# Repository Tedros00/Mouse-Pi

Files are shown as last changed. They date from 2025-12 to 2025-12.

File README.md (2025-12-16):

# Mouse-Pi

A compact, self-contained repository for the Mouse-Pi autonomous mobile robotics project. This README summarizes the repository purpose, quick-start instructions, and the folder layout so contributors and maintainers can find relevant code, models, and hardware files quickly.

## Quick start
- Install Python dependencies: run `pip install -r requirements.txt` in a suitable venv.
- Simulation: open the Gazebo worlds in `Gazebo/worlds/` and run the scripts in `Gazebo/scripts/`.
- Development: most robot algorithms and helpers live in `src/` and `examples/` — open those to run localization, SLAM, and planning examples.
- Embedded firmware: use PlatformIO workspace in `PlatformIO/` to build and flash microcontroller code.

## Folder structure
- `3D parts/` : SolidWorks assemblies, parts and exported STLs for 3D printing and mechanical design.
	- `SW/` contains individual SolidWorks part files.
- `Gazebo/` : Simulation assets (worlds, models, and helper scripts).
	- `models/robot/` contains the robot model used by Gazebo.
	- `scripts/` contains launch and utility scripts (e.g., `ekf.py`, `plan.py`).
- `PC/` : Host/PC-specific code and tools (if present, tools for mapping/visualization).
- `Pi/` : Pi-side scripts and deployment notes for running on Raspberry Pi.
- `examples/` : Example scripts grouped by purpose: Sensors, Interfaces, Models, SimulationEnv — useful starting points and demos.
- `PlatformIO/` : Embedded firmware source and configuration (`platformio.ini`, `src/`).
- `requirements.txt` : Python dependencies for simulation and algorithms.
- `results/` : Output artifacts such as generated maps and logs (e.g., `map.npy`, `trajectory.csv`).

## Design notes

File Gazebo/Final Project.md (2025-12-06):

# Final Project — Maze SLAM & Relocalization Challenge




## Overview
You will be given a **physical maze**. Your job is to:
1) **Build a simulated twin** of that maze in Gazebo using **`.sdf`** (simulate what you will test physically).
2) Make a mobile robot that can:
   - **Task A (Exploration + Mapping):** When released at a random pose, autonomously navigate and **build a map** of the environment.
   - **Task B (Relocalization + Goal Reach):** After the map exists, place the robot at a new, random pose; it must **relocalize** and **reach a specified target**.

You may use **any hardware/software** you like (ROS or NON ROS), but based on the LEGO NXT ROBOT. Teams with the **best time** (and valid maps) win.

## Learning Goals
- Apply **mobile-robot kinematics & control** to navigate safely (e.g., differential-drive constraints, nonholonomy).
- Implement **recursive state estimation** (prediction + update) for localization and mapping.
- Compare/choose between **Gaussian filters** (EKF/UKF) and **non‑parametric filters** (Particle) for SLAM and global relocalization.

---

## Project Tasks

### 1) Simulation Twin (SDF)
- Model the maze as an **SDF world** with proper wall geometry and friction; include your robot model and sensors (e.g., 2D lidar, IMU, other sensors...).
- Automate (With LLMs) a **reproducible launch** (ROS 2 or equivalent) that boots the world and your stack.

### 2) Task A — Exploration & Mapping
- From a **random initial pose**, the robot should **autonomously explore** and **produce a consistent map** (grid/occupancy or feature‑based).
- Use a **recursive estimator** with motion and measurement models (odometry/IMU + range/vision). Show prediction → correction clearly in your code/report.
- Deliver a **final map ** (e.g., picture or table format). 

### 3) Task B — Relocalization & Target Reach
- With the map available, start the robot at a **new random pose**; perform **global relocalization** and then **navigate** to a **given goal** (x, y, θ or zone).
- Robust global relocalization is encouraged to use **particle filters** (Monte Carlo Localization) (Through ROS2 or Custom)

---

## Constraints & Rules
- **Randomization:** Starting pose will be randomized in both A and B; your procedure must not depend on hard‑coded starts.
- **Sensing:** Any sensor suite is allowed; document models/noise. The estimator must fuse **control (uₜ)** and **measurements (zₜ)**.
- **Safety:** No collisions in sim, penalize sustained wall scraping; in lab, use a safe speed limit.
- **Reproducibility:** One‑command launch for sim and for system.

---

## What to Deliver

### Code & Simulation
- Public or zipped repo:
  - `worlds/maze.sdf` (`.sdf`) + any models
  - `launch/` scripts (ROS 2 or python or equivalent)
  - `README.md` with setup, **exact run commands**, and expected outputs

### Demonstrations
- **Sim demo:** Short screen‑capture: Task A (mapping) + Task B (relocalize & reach goal).
- **Physical demo:** Same two tasks on the real maze. You may pre‑map with your sim twin, but the **final judged map** must come from the physical run in Task A.

### Report (Explaining your strategy)
1. **Problem & system overview** (robot, sensors, actuation, kinematics).  
2. **Models:** motion model, sensor model, and **Bayes filter** formulation (state, control, measurement, belief).  
3. **Estimator choice:** KF/EKF/UKF vs Particle; justify with **linearity**, **uncertainty**, **multimodality**.  
4. **Mapping:** occupancy‑grid (log‑odds) or feature map; include update equations.  
5. **Navigation & control:** planner + controller; note non‑holonomic constraints if diff‑drive.  
6. **Experiments:** timing tables, success rate, map quality metrics (see below), failure cases, parameter sweeps.
7. **Ablations:** e.g., effect of particle count vs. convergence time; EKF vs UKF linearization quality.

---

## Scoring & Competition

### Timing (50%)
- **Task A time (20%)**: release → **map complete** (frontier exhausted or coverage ≥ 95%). Faster is better.
- **Task B time (20%)**: placement → **goal reached** within tolerance (e.g., ≤10 cm, ≤10°).
- **Start‑to‑finish integration (10%)**: minimal operator intervention; clean launch; robust recovery.

### Quality (30%)
- **Map quality (15%)**: occupancy grid IoU vs reference (or repeatability across two runs ± noise).
- **Localization accuracy (10%)**: final pose error at goal (or RMSE over a fiducial‑tracked segment).
- **Navigation smoothness (5%)**: path length vs shortest path; collision penalties.

### Engineering & Report (20%)
- **Clarity of models & estimators** (Bayes filter structure; linear vs nonlinear assumptions).  
- **Code quality & reproducibility** (README, configs, parameterization).  
- **Insightful analysis** (what worked/failed, evidence‑based choices).

**Penalties:** hard‑coded starts, non‑reproducible launches, unsafe behavior, large drift without recovery.  
**Tiebreakers:** smaller compute budget (CPU‑only vs GPU), cleaner code, clearer write‑up.

---

## Suggested Technical Path (Optional)
- **Kinematics & control:** Respect non‑holonomic constraints; implement a velocity controller and pose‑tracking law for your base.
- **Estimator selection:**
  - **EKF/UKF** if your models are near‑linear locally and you expect **unimodal** beliefs.
  - **Particle Filter** (MCL/AMCL‑like) if you expect **global uncertainty** or **multiple pose hypotheses** during relocalization; mind resampling and variance.
- **Mapping:** **Occupancy grid** with binary Bayes/Log‑odds updates; fuse lidar/range beams with inverse sensor models.
- **Exploration:** Frontier‑based or wall‑following with loop closures if available.
- **Validation:** Compare sim vs real logs; run with increased sensor noise to test robustness.  
- **Performance:** Tune particle count vs latency; for Gaussian filters, check linearization regime and innovation consistency.

---

## Logistics
- **Teams:** 2–3 students.
- **What to submit (single ZIP + PDF):**
  - Code repo (as above), **built map files**, short **sim video** (≤2 min), **report PDF** (≤6 pages).
- **Demo day:** Live **physical** runs for Task A and B on the lab maze under staff timing.
- **Academic integrity:** Cite all external packages and models you use.

---

### RPI HARDWARE

-USB C Cable for powering (5A high power)
-Power Bank To power remotely
-microSD card (A1/A2, 32–128 GB) + USB card reader
-micro-HDMI → HDMI cable (two if dual display)
-Active cooler or case with fan
-Raspberry Pi Camera Module 3 (Optional If you need visual feedback)

### Room Policy

-1 member per team gets room access.
-Don't use hardware not for the course (drones, other PIs, room hardware)

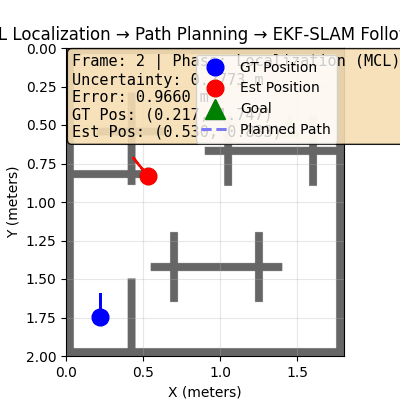
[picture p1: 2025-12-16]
out/PathPlan.gif

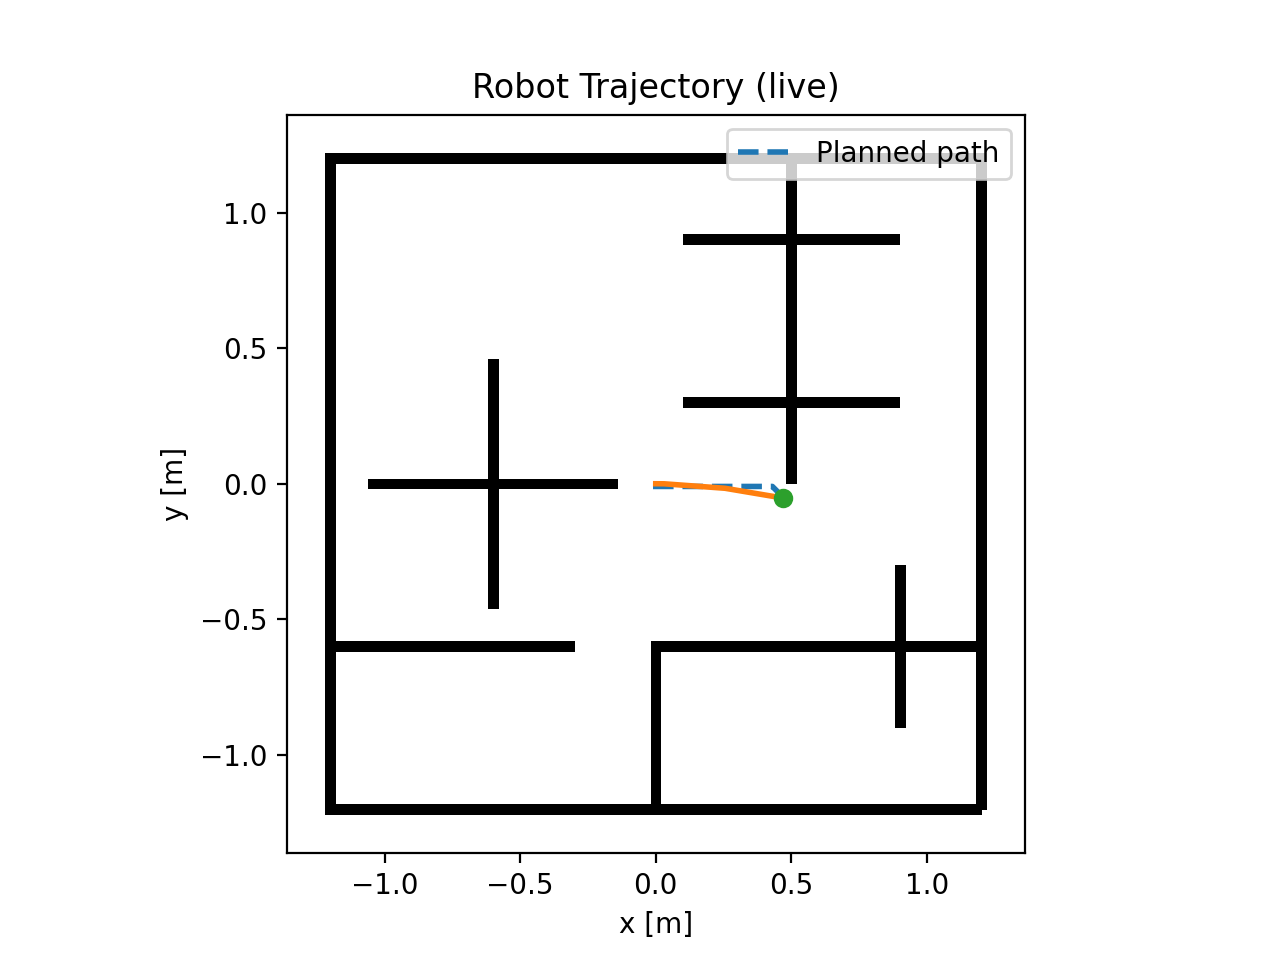
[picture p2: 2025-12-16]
Gazebo/scripts/trajectory.png

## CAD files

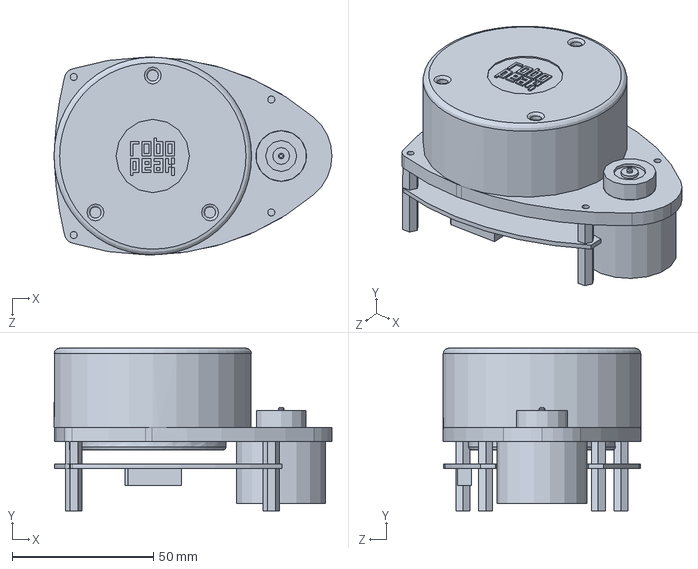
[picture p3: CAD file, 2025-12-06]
3D parts/SW/rplidar_main.SLDPRT
98.5 x 57.7 x 70.0 mm

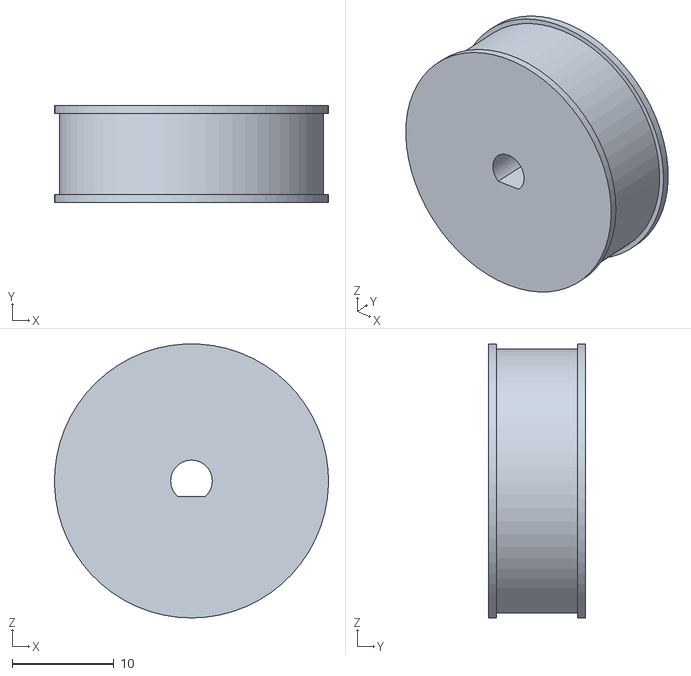
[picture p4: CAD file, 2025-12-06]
3D parts/STL/Motor pinion.STL
27.0 x 9.60 x 27.0

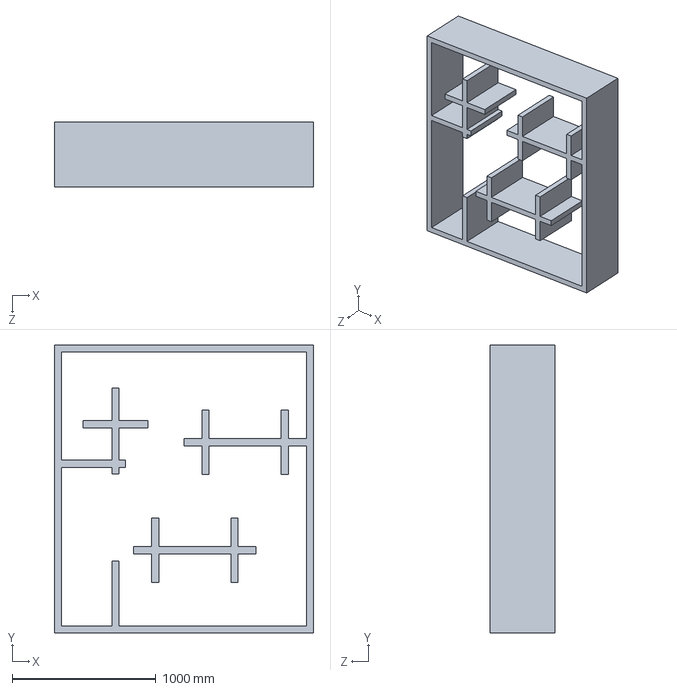
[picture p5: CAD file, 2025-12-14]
3D parts/SW/Maze.SLDPRT
1800.0 x 2000.0 x 450.0 mm

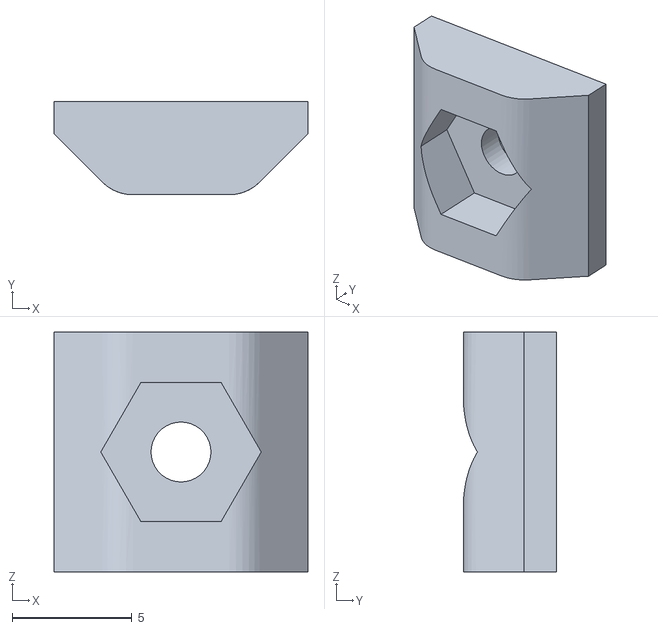
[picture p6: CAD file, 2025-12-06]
3D parts/STL/rack mount.STL
10.6 x 3.90 x 10.0

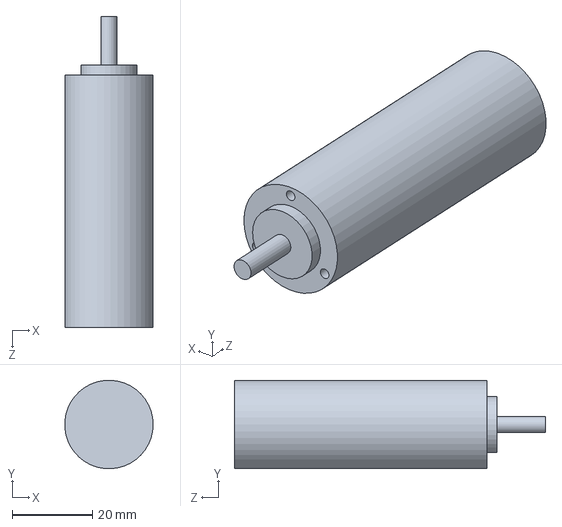
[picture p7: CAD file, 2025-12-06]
3D parts/SW/Motor.SLDPRT
22.0 x 22.0 x 77.3 mm

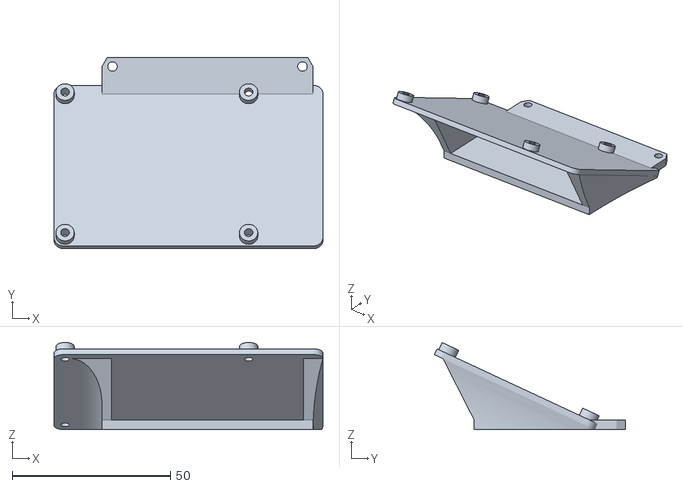
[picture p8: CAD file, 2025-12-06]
3D parts/STL/Pi mount.STL
85.0 x 60.5 x 27.5

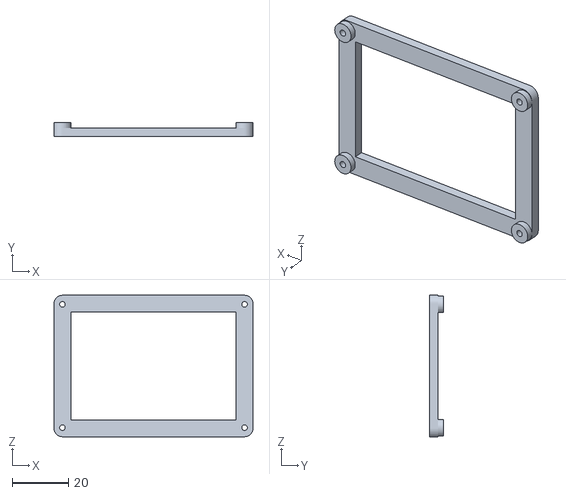
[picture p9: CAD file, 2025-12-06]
3D parts/STL/arduino mount.STL
71.0 x 5.00 x 50.5

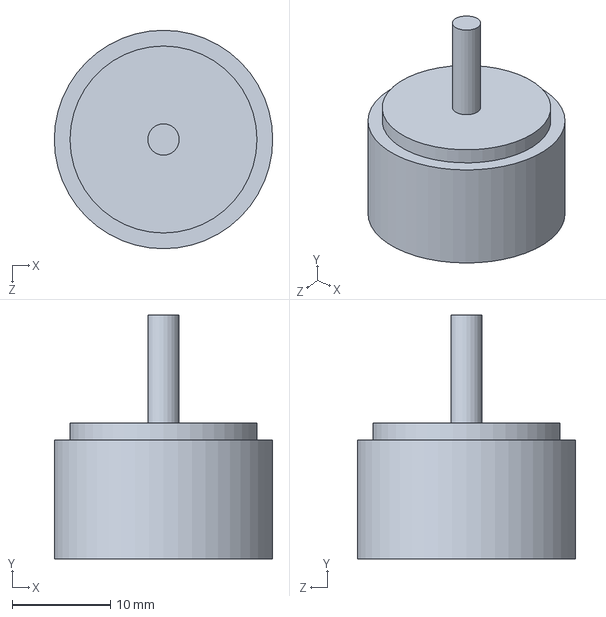
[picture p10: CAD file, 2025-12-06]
3D parts/SW/pot.SLDPRT
22.2 x 24.8 x 22.2 mm

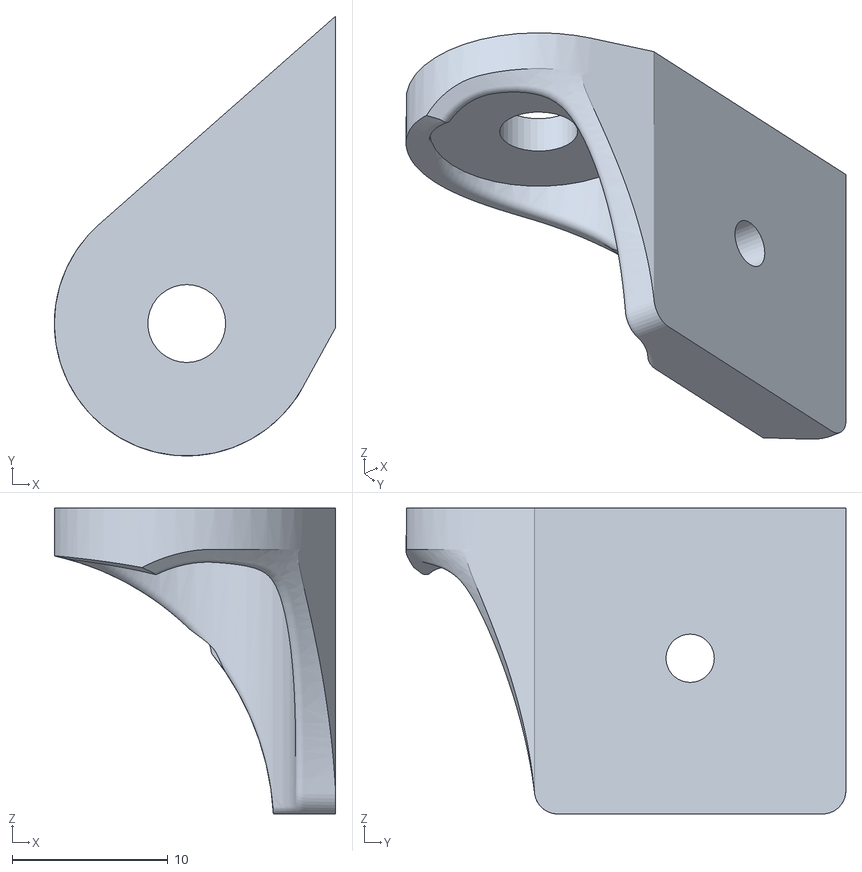
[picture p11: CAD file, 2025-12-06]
3D parts/STL/barrel mount.STL
18.1 x 28.2 x 19.6

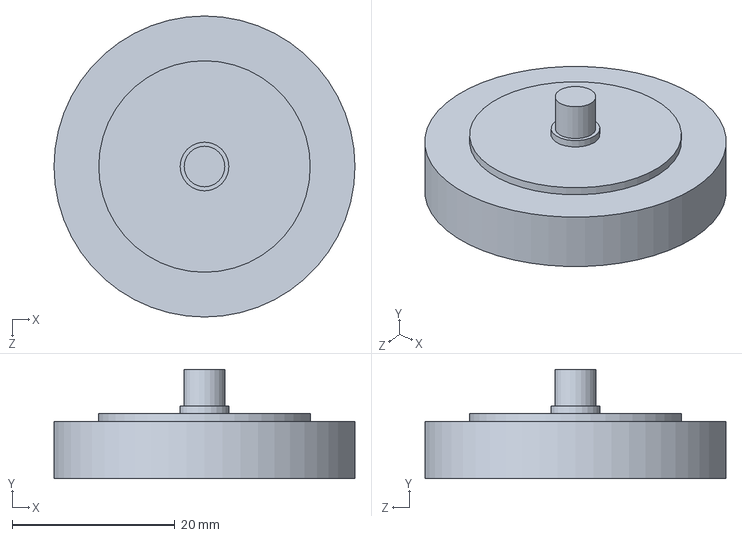
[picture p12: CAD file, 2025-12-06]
3D parts/SW/wheel.SLDPRT
37.0 x 13.4 x 37.0 mm

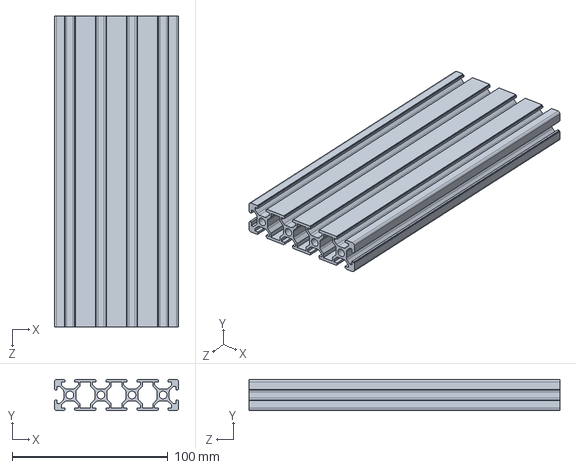
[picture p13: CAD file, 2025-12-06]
3D parts/SW/2080 Extrusion.SLDPRT
80.0 x 20.0 x 200.0 mm

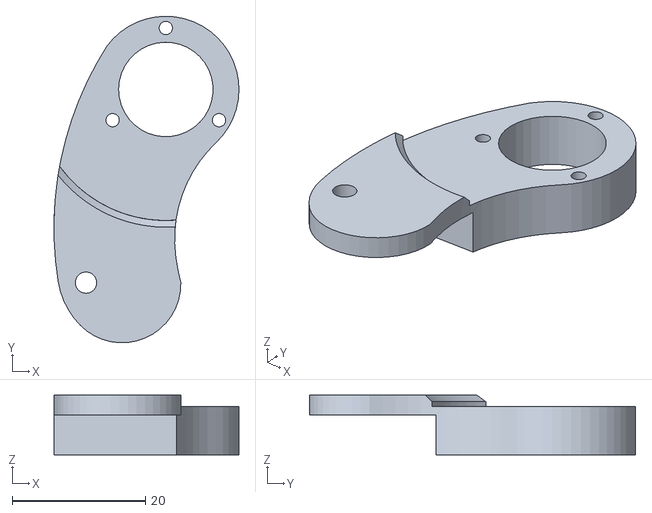
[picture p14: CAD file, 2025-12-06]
3D parts/STL/Motor Mount.STL
27.8 x 49.1 x 9.00

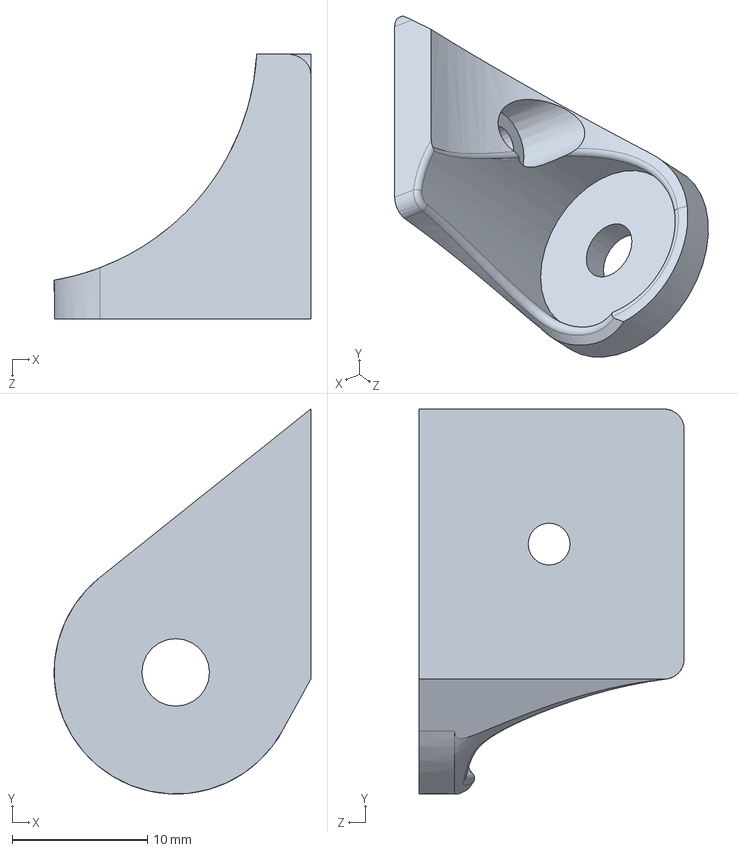
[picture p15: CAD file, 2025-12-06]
3D parts/SW/barrel mount.SLDPRT
19.0 x 28.5 x 19.6 mm

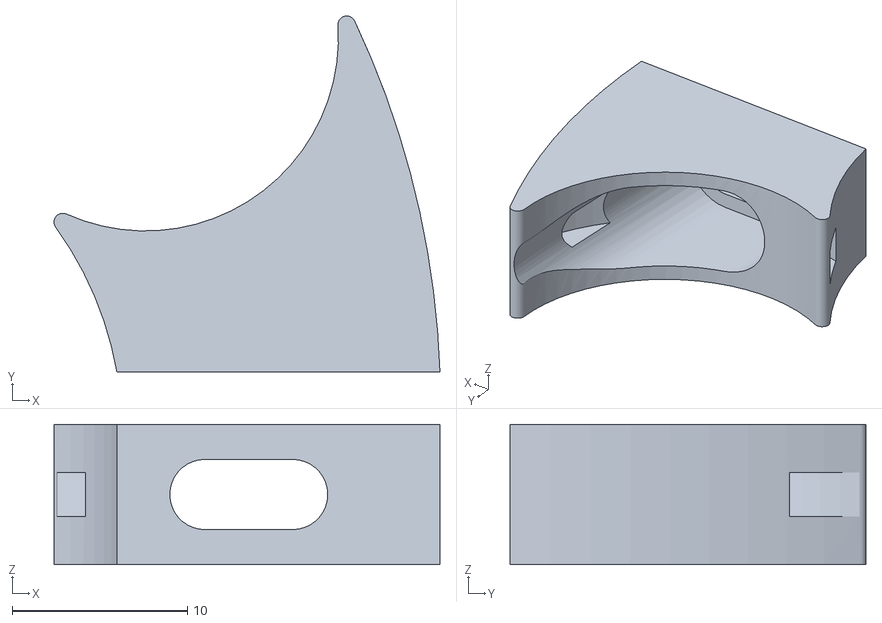
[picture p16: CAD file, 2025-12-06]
3D parts/STL/motor support.STL
22.0 x 20.3 x 8.00

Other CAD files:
3D parts/mouse.SLDASM
3D parts/SW/RaspberryPi5.SLDPRT
3D parts/STL/LidarMount.STL
3D parts/SW/arduino mount.SLDPRT
3D parts/STL/T-nut adapter.STL
3D parts/SW/T-nut adapter.SLDPRT
3D parts/SW/barrel.SLDPRT
3D parts/SW/motor pinion.SLDPRT

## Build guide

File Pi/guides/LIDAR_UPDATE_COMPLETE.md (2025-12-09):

# LIDAR Visualization Update - Complete Summary

## Overview

Your LIDAR streaming and visualization system has been completely upgraded to show **robot pose**, **scan statistics**, and **beam range finder model integration**.

## What's New ✨

### 1. Robot Pose Visualization
- Robot position displayed as **red circle**
- Robot heading shown with **red arrow**
- Automatic world-frame coordinate transformation
- Dynamic view that follows the robot

### 2. Scan Statistics
Each streamed frame now includes:
- **Distance metrics**: min, max, mean, median, standard deviation
- **Quality metrics**: minimum, maximum, mean signal strength
- **Point count**: number of valid measurements
- **Beam coverage**: percentage of beams with valid data

### 3. Beam Range Finder Model Integration
- **Normalized ranges** (0-1 scale) computed for all 360 beams
- Can be directly used with `beam_range_finder_model()`
- Optional beam coverage visualization (cyan lines)

### 4. Two Visualization Options

#### Option A: Simple (Fast)
```bash
python visualize_lidar_stream.py
```
- Single plot with scan points
- Robot pose overlay
- Basic statistics in title
- Low CPU usage

#### Option B: Advanced (Comprehensive)
```bash
python visualize_lidar_advanced.py
```
- 4-panel dashboard
- Distance distribution histogram
- Quality vs distance scatter plot
- Comprehensive statistics panel
- Beam coverage visualization

## Quick Start

### Step 1: Update Script with Your PC IP
Edit `examples/stream_lidar_to_pc.py`:
```python
PC_IP = '192.168.x.x'  # Your PC's IP address
```

### Step 2: Start Visualization on PC
```bash
# Choose one:
python visualize_lidar_stream.py         # Simple
python visualize_lidar_advanced.py       # Dashboard
```

### Step 3: Start Streaming on Robot
```bash
source /home/mouse/amr/bin/activate
python examples/stream_lidar_to_pc.py
```

### Step 4: Watch Real-time Data Flow
The visualization updates with:
- Scan points at current robot position
- Distance and quality statistics
- Frame counters and timestamps

## File Changes

### Modified Files
1. **`examples/stream_lidar_to_pc.py`**
   - Complete rewrite with pose/statistics support
   - New: `stream_lidar_with_pose()` function
   - New: Robot pose callback system
   - Sends: pose + stats + ranges per frame

2. **`examples/visualize_lidar_stream.py`**
   - Added robot pose visualization
   - Added statistics display
   - World-frame coordinate transformation
   - Dynamic axis scaling

### New Files
1. **`examples/visualize_lidar_advanced.py`**
   - 4-panel dashboard visualization
   - Distance distribution analysis
   - Quality metrics scatter plot
   - Comprehensive statistics panel

2. **`examples/validate_lidar_visualization.py`**
   - Comprehensive validation tests
   - Tests all components work together
   - Validates JSON serialization
   - All tests passing ✅

3. **Documentation Files**
   - `LIDAR_VISUALIZATION_README.md` - Detailed guide
   - `LIDAR_QUICK_START.py` - Quick reference
   - `LIDAR_VISUALIZATION_UPDATE.md` - Change summary

## Integration with Odometry

Update the `get_robot_pose()` callback in `stream_lidar_to_pc.py`:

```python
def get_robot_pose():
    # Option 1: From your motion model
    x, y, theta = your_motion_model.estimate_pose()
    
    # Option 2: From encoder feedback
    # x, y, theta = encoder_system.get_position()
    
    # Option 3: From particle filter
    # x, y, theta = particle_filter.get_best_estimate()
    
    return (x, y, theta)
```

The streaming automatically includes your pose estimates in every frame.

## Using with Beam Range Finder Model

The streamed `normalized_ranges` can be directly used:

```python
from ProbabilisticSensorModel import beam_range_finder_model
import numpy as np

# From streamed frame data
normalized_ranges = frame['normalized_ranges']
denormalized = np.array(normalized_ranges) * 5000  # Convert to mm

# Evaluate likelihood for particle filter
prob = beam_range_finder_model(
    robot_pose=(frame['robot_pose']['x'], 
                frame['robot_pose']['y'],
                frame['robot_pose']['theta']),
    z=denormalized,
    map_data=your_map,
    compute_from_map=your_ray_cast_function,
    max_range=5000
)

# Use probability for particle weighting
particle_weights[i] = prob
```

## Data Format

Each frame contains:
```json
{
  "timestamp": 1702190000.123,
  "frame": 42,
  "robot_pose": {"x": 100, "y": 200, "theta": 0.5},
  "num_points": 1000,
  "points": [[angle, distance, quality], ...],
  "statistics": {
    "min_distance": 200,
    "max_distance": 5000,
    "mean_distance": 1200,
    "median_distance": 1000,
    "std_distance": 400,
    "quality_mean": 12.5,
    "quality_min": 0,
    "quality_max": 15
  },
  "normalized_ranges": [0.1, 0.11, ..., 0.09]
}
```

## Performance

| Metric | Value |
|---|---|
| Data per frame | ~50KB |
| Update rate | 5-10 Hz |
| Network bandwidth | ~500KB/s |
| CPU (simple viz) | ~5% |
| CPU (dashboard) | ~15% |

## Testing Status

✅ All validation tests passed:
- Stream data format
- Pose transformation
- Statistics computation
- Normalized ranges
- Visualization compatibility

## What the Visualizations Show

### Simple Visualization
```
┌──────────────────────┐
│  Scan Points (dots)  │
│  - Colored by quality │
│  - Red circle = robot│
│  - Red arrow = heading
│  - Statistics in title
└──────────────────────┘
```

### Advanced Dashboard
```
┌──────────────────┬──────────────────┐
│ Scan Viz         │ Distance Hist    │
│ + Robot Pose     │ + Mean/Median    │
├──────────────────┼──────────────────┤
│ Quality vs Dist  │ Statistics Panel │
│ (Scatter plot)   │ (Text Info)      │
└──────────────────┴──────────────────┘
```

## Known Limitations & Solutions

| Issue | Solution |
|---|---|
| Beam coverage not visible | Increase alpha in `draw_beam_coverage()` |
| Slow on low-end PC | Use simple visualization instead |
| Statistics seem wrong | Verify LIDAR filters and odometry |
| Connection fails | Start visualization before streaming |

## Next Steps

1. ✅ **Test with current setup** - Works out of the box at origin
2. 🔄 **Add your odometry** - Implement `get_robot_pose()` callback
3. 📊 **Validate statistics** - Compare with known environments
4. 🗺️ **Add map overlay** - Extend visualization with obstacle map
5. 🔍 **Tune beam model** - Use statistics to validate sensor parameters

## Files You Need to Know

**Robot Side:**
- `examples/stream_lidar_to_pc.py` - Run on AMR

**PC Side (Pick One):**
- `examples/visualize_lidar_stream.py` - Simple, fast
- `examples/visualize_lidar_advanced.py` - Detailed analysis

**Testing/Validation:**
- `examples/validate_lidar_visualization.py` - Verify everything works

**Documentation:**
- `LIDAR_VISUALIZATION_README.md` - Full reference
- `LIDAR_QUICK_START.py` - Code examples
- `LIDAR_VISUALIZATION_UPDATE.md` - Change log

## Support & Debugging

**Check console output on robot:**
```
Frame 5: 1000 points | Distance: 1200±400mm | Pose: (0.0, 0.0, 0.0°)
Frame 10: 995 points | Distance: 1210±410mm | Pose: (100.0, 50.0, 15.2°)
```

**Common fixes:**
1. Connection refused → Start visualization first
2. No points visible → Check LIDAR connected, pose reasonable
3. Statistics wrong → Verify filters, odometry callback
4. Slow updates → Use simple viz, reduce update frequency

## Summary

You now have a complete real-time LIDAR visualization system with:
- ✅ Robot pose tracking
- ✅ Comprehensive statistics
- ✅ Beam range finder model integration
- ✅ Two visualization levels (simple + advanced)
- ✅ Easy odometry integration
- ✅ World-frame coordinate display
- ✅ Full validation testing

Ready to use! 🚀

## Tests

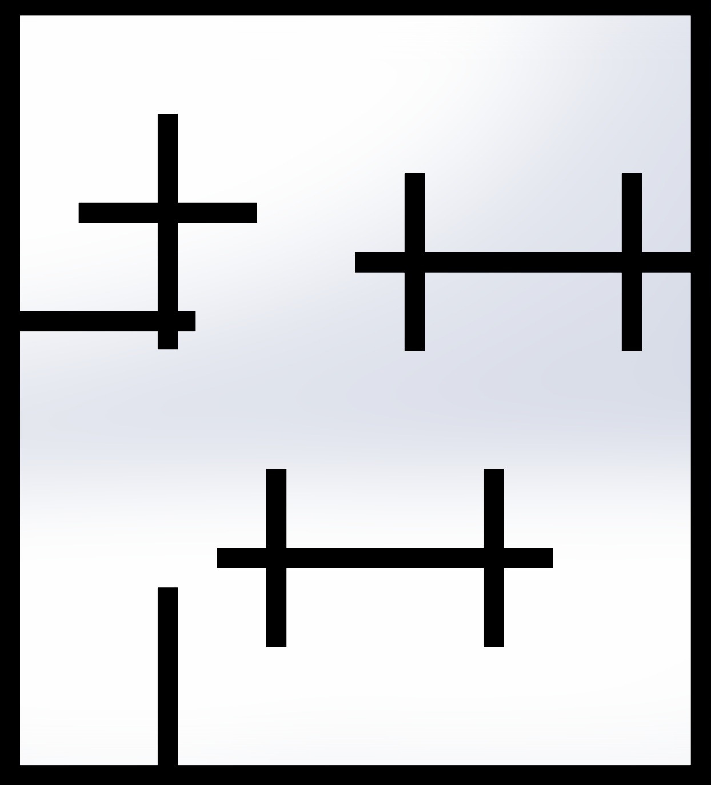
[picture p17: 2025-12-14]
Pi/examples/SimulationEnv/TestMaze.JPG

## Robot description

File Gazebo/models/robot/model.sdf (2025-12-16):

<?xml version="1.0"?>
<sdf version="1.9">
  <model name="robot">

    <pose>0 0 0.05 0 0 0</pose>

    <!-- ================= BASE ================= -->
    <link name="base_link">
      <pose>0 0 0.05 0 0 0</pose>

      <inertial>
        <mass>1.5</mass>
        <inertia>
          <ixx>0.02</ixx>
          <iyy>0.02</iyy>
          <izz>0.04</izz>
        </inertia>
      </inertial>

      <collision name="base_collision">
        <geometry>
          <box>
            <size>0.18 0.14 0.10</size>
          </box>
        </geometry>
      </collision>

      <visual name="base_visual">
        <geometry>
          <box>
            <size>0.18 0.14 0.10</size>
          </box>
        </geometry>
        <material>
          <ambient>0.8 0.8 0.8 1</ambient>
          <diffuse>0.8 0.8 0.8 1</diffuse>
        </material>
      </visual>

      <!-- IMU -->
      <sensor name="imu" type="imu">
        <always_on>true</always_on>
        <update_rate>200</update_rate>
        <topic>/model/robot/imu</topic>
      </sensor>

      <!-- GPS -->
      <sensor name="gps" type="gps">
        <always_on>true</always_on>
        <update_rate>5</update_rate>
        <topic>/model/robot/gps</topic>
      </sensor>

      <!-- 2D LIDAR -->
      <sensor name="lidar" type="gpu_lidar">
        <pose>0.09 0 0.12 0 0 0</pose>
        <update_rate>10</update_rate>
        <topic>/scan</topic>

        <lidar>
          <scan>
            <horizontal>
              <samples>720</samples>
              <min_angle>-3.14159</min_angle>
              <max_angle>3.14159</max_angle>
            </horizontal>
          </scan>
          <range>
            <min>0.05</min>
            <max>6.0</max>
          </range>
        </lidar>
      </sensor>
    </link>

    <!-- ================= LEFT WHEEL ================= -->
    <link name="left_wheel">
      <!-- IMPORTANT: roll = 1.5708 to align cylinder axis with Y -->
      <pose>0 0.07 0.03 1.5708 0 0</pose>

      <inertial>
        <mass>0.2</mass>
        <inertia>
          <ixx>0.001</ixx>
          <iyy>0.001</iyy>
          <izz>0.001</izz>
        </inertia>
      </inertial>

      <collision name="collision">
        <geometry>
          <cylinder>
            <radius>0.03</radius>
            <length>0.02</length>
          </cylinder>
        </geometry>
      </collision>

      <visual name="visual">
        <geometry>
          <cylinder>
            <radius>0.03</radius>
            <length>0.02</length>
          </cylinder>
        </geometry>
        <material>
          <ambient>0.1 0.1 0.1 1</ambient>
        </material>
      </visual>
    </link>

    <!-- ================= RIGHT WHEEL ================= -->
    <link name="right_wheel">
      <pose>0 -0.07 0.03 1.5708 0 0</pose>

      <inertial>
        <mass>0.2</mass>
        <inertia>
          <ixx>0.001</ixx>
          <iyy>0.001</iyy>
          <izz>0.001</izz>
        </inertia>
      </inertial>

      <collision name="collision">
        <geometry>
          <cylinder>
            <radius>0.03</radius>
            <length>0.02</length>
          </cylinder>
        </geometry>
      </collision>

      <visual name="visual">
        <geometry>
          <cylinder>
            <radius>0.03</radius>
            <length>0.02</length>
          </cylinder>
        </geometry>
        <material>
          <ambient>0.1 0.1 0.1 1</ambient>
        </material>
      </visual>
    </link>

    <!-- ================= JOINTS ================= -->
    <joint name="left_wheel_joint" type="revolute">
      <parent>base_link</parent>
      <child>left_wheel</child>
      <axis>
        <xyz>0 1 0</xyz>
      </axis>
    </joint>

    <joint name="right_wheel_joint" type="revolute">
      <parent>base_link</parent>
      <child>right_wheel</child>
      <axis>
        <xyz>0 1 0</xyz>
      </axis>
    </joint>

    <!-- ================= DIFF DRIVE ================= -->
    <plugin filename="gz-sim-diff-drive-system" name="gz::sim::systems::DiffDrive">

      <left_joint>left_wheel_joint</left_joint>
      <right_joint>right_wheel_joint</right_joint>

      <wheel_separation>0.14</wheel_separation>
      <wheel_radius>0.03</wheel_radius>

      <cmd_vel_topic>/model/robot/cmd_vel</cmd_vel_topic>
      <odom_topic>/model/robot/odom</odom_topic>
      <odom_publish_frequency>50</odom_publish_frequency>

      <publish_tf>false</publish_tf>
    </plugin>

  </model>
</sdf>

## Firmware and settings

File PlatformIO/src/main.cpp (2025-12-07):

#include <Arduino.h>

// Motor A (connected to EN_A, IN1, IN2)
#define EN_A A0
#define IN1 11
#define IN2 10

// Motor B (connected to EN_B, IN3, IN4)
#define EN_B A1
#define IN3 7
#define IN4 8

// PWM Frequency control
// Lowering frequency gives more torque at low speeds but may cause buzzing
// Higher frequency is smoother but may need higher minimum PWM
#define PWM_FREQUENCY 490  // Default Arduino frequency; try 122, 245, 490, 980, 3920, 7840, 15625 Hz

// Potentiometers
#define POT1 A2
#define POT2 A3

// Forward declaration of PWM frequency function
void setPwmFrequency(int pin, int divisor);

void setup() {
  Serial.begin(115200);  // Initialize serial communication at 115200 baud
  
  // Configure motor control pins as outputs
  pinMode(EN_A, OUTPUT);
  pinMode(IN1, OUTPUT);
  pinMode(IN2, OUTPUT);
  
  pinMode(EN_B, OUTPUT);
  pinMode(IN3, OUTPUT);
  pinMode(IN4, OUTPUT);
  
  // Configure potentiometers as inputs
  pinMode(POT1, INPUT);
  pinMode(POT2, INPUT);
  
  // Set PWM frequency for motor pins (pins 9 and 10 share timer1, 3 and 11 share timer2)
  // For pins 11 (IN2/EN_A) and 3 (IN4/EN_B): change timer2 frequency
  setPwmFrequency(11, 1);  // Divider 1 = 31.4 kHz (too high, audible noise reduced)
  setPwmFrequency(3, 1);   // Divider 1 = 31.4 kHz
  
  // Initialize motors to stop
  digitalWrite(IN1, LOW);
  digitalWrite(IN2, LOW);
  digitalWrite(IN3, LOW);
  digitalWrite(IN4, LOW);
  analogWrite(EN_A, 0);
  analogWrite(EN_B, 0);
}

void setMotor(int pwmPin, int in1Pin, int in2Pin, int dutyCycle) {
  // dutyCycle ranges from -100 to 100
  // Positive values: IN1 HIGH, IN2 LOW
  // Negative values: IN1 LOW, IN2 HIGH
  
  // Define minimum and maximum PWM values for motor control
  // MIN_PWM: minimum speed threshold to start motor rotation (adjust to your motor's needs)
  // MAX_PWM: typically 255, but can be reduced to limit maximum speed
  const int MIN_PWM = 36;    // You found motors activate at 36
  const int MAX_PWM = 255;
  
  // Map duty cycle to PWM range with dead band
  int pwmValue = 0;
  if (dutyCycle != 0) {
    // Map 1-100% to MIN_PWM-MAX_PWM range
    pwmValue = MIN_PWM + (abs(dutyCycle) - 1) * (MAX_PWM - MIN_PWM) / 99;
    pwmValue = constrain(pwmValue, MIN_PWM, MAX_PWM);
  }
  
  if (dutyCycle > 0) {
    // Forward direction
    digitalWrite(in1Pin, HIGH);
    digitalWrite(in2Pin, LOW);
  } else if (dutyCycle < 0) {
    // Reverse direction
    digitalWrite(in1Pin, LOW);
    digitalWrite(in2Pin, HIGH);
  } else {
    // Stop
    digitalWrite(in1Pin, LOW);
    digitalWrite(in2Pin, LOW);
  }
  
  analogWrite(pwmPin, pwmValue);
}

void loop() {
  // Read potentiometer values
  int pot1Value = analogRead(POT1);
  int pot2Value = analogRead(POT2);
  
  // Print potentiometer values
  Serial.print("Pot1: ");
  Serial.print(pot1Value);
  Serial.print(" | Pot2: ");
  Serial.println(pot2Value);
  
  if (Serial.available() > 0) {
    // Read the input string until newline
    String input = Serial.readStringUntil('\n');
    input.trim();
    
    // Parse the two integers
    int spaceIndex = input.indexOf(' ');
    
    if (spaceIndex > 0) {
      int dc1 = input.substring(0, spaceIndex).toInt();
      int dc2 = input.substring(spaceIndex + 1).toInt();
      
      // Constrain values to -100 to 100
      dc1 = constrain(dc1, -100, 100);
      dc2 = constrain(dc2, -100, 100);
      
      // Set motor speeds
      setMotor(EN_A, IN1, IN2, dc1);
      setMotor(EN_B, IN3, IN4, dc2);
      
      // Echo back the values for confirmation
      Serial.print("Motor A: ");
      Serial.print(dc1);
      Serial.print("% | Motor B: ");
      Serial.print(dc2);
      Serial.println("%");
    }
  }
  
  delay(100);  // Print potentiometer values every 100ms
}

// Set PWM frequency on Arduino pins
// Divisor: 1=31.4kHz, 2=3.9kHz, 3=980Hz, 4=490Hz, 5=245Hz, 6=122Hz, 7=61Hz
void setPwmFrequency(int pin, int divisor) {
  byte mode;
  if(pin == 5 || pin == 6 || pin == 9 || pin == 10) {
    switch(divisor) {
      case 1: mode = 0x01; break;
      case 2: mode = 0x02; break;
      case 3: mode = 0x03; break;
      case 4: mode = 0x04; break;
      case 5: mode = 0x05; break;
      case 6: mode = 0x06; break;
      case 7: mode = 0x07; break;
      default: return;
    }
    TCCR1B = (TCCR1B & 0b11111000) | mode;
  }
  else if(pin == 3 || pin == 11) {
    switch(divisor) {
      case 1: mode = 0x01; break;
      case 2: mode = 0x02; break;
      case 3: mode = 0x03; break;
      case 4: mode = 0x04; break;
      case 5: mode = 0x05; break;
      case 6: mode = 0x06; break;
      case 7: mode = 0x07; break;
      default: return;
    }
    TCCR2B = (TCCR2B & 0b11111000) | mode;
  }
}

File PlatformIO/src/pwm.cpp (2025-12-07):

#include <Arduino.h>

// Motor A (connected to EN_A, IN1, IN2)
#define EN_A A0
#define IN1 11
#define IN2 10

// Motor B (connected to EN_B, IN3, IN4)
#define EN_B A1
#define IN3 7
#define IN4 8

// Potentiometers
#define POT1 A2
#define POT2 A3

// ============================================================================
// Hardware PWM Interrupt-Based Control
// ============================================================================

// PWM Configuration
const uint16_t PWM_FREQUENCY_HZ = 10000;           // PWM frequency in Hz

// PWM state for each motor (0-255, where 0=0% duty, 255=100% duty)
volatile uint8_t pwm_motor_a = 0;  // Motor A PWM value (0-255)
volatile uint8_t pwm_motor_b = 0;  // Motor B PWM value (0-255)

// PWM direction control (true = positive direction, false = negative direction)
volatile bool dir_motor_a = true;   // true: IN1 gets PWM, false: IN2 gets PWM
volatile bool dir_motor_b = true;   // true: IN3 gets PWM, false: IN4 gets PWM

// Internal timing state for interrupt handler
volatile uint16_t pwm_timer_count = 0;  // Current timer tick count within PWM period

// ============================================================================
// Timer1 Interrupt Handler - Runs at 16kHz (62.5us intervals)
// Generates PWM signals based on current pwm_motor_a and pwm_motor_b values
// ============================================================================
ISR(TIMER1_COMPA_vect) {
  // Motor A control: EN_A gets PWM, IN1/IN2 set direction
  if (pwm_timer_count <= pwm_motor_a) {
    digitalWrite(EN_A, HIGH);  // Enable motor (PWM high)
  } else {
    digitalWrite(EN_A, LOW);   // Disable motor (PWM low)
  }
  
  // Set direction for Motor A
  if (dir_motor_a) {
    digitalWrite(IN1, HIGH);   // Forward direction
    digitalWrite(IN2, LOW);
  } else {
    digitalWrite(IN1, LOW);    // Reverse direction
    digitalWrite(IN2, HIGH);
  }
  
  // Motor B control: EN_B gets PWM, IN3/IN4 set direction
  if (pwm_timer_count <= pwm_motor_b) {
    digitalWrite(EN_B, HIGH);  // Enable motor (PWM high)
  } else {
    digitalWrite(EN_B, LOW);   // Disable motor (PWM low)
  }
  
  // Set direction for Motor B
  if (dir_motor_b) {
    digitalWrite(IN3, HIGH);   // Forward direction
    digitalWrite(IN4, LOW);
  } else {
    digitalWrite(IN3, LOW);    // Reverse direction
    digitalWrite(IN4, HIGH);
  }
  
  // Increment timer counter and reset at period end
  pwm_timer_count++;
  if (pwm_timer_count >= 256) {
    pwm_timer_count = 0;
  }
}

// ============================================================================
// Public API Functions
// ============================================================================

/**
 * Initialize Timer1 for PWM interrupt-based control
 * Sets up CTC mode with interrupts at 16kHz
 */
void pwm_init() {
  // Timer1 Configuration for CTC mode
  TCCR1A = 0;                     // Normal mode
  TCCR1B = 0;                     // Reset
  TCNT1 = 0;                      // Reset counter
  
  // Set CTC mode (WGM12 = 1)
  TCCR1B |= (1 << WGM12);
  
  // Set prescaler to 1 (no prescaling) for 16MHz -> 16MHz ticks
  TCCR1B |= (1 << CS10);
  
  // Set compare value for 16kHz interrupt (16000000 / 16000 = 1000 ticks)
  OCR1A = 1000;
  
  // Enable Timer1 Compare A interrupt
  TIMSK1 |= (1 << OCIE1A);
}

/**
 * Set PWM value for Motor A
 * @param pwm_value: 0-255 (0% to 100% duty cycle)
 *        Sign determines direction: positive -> IN1 active, negative -> IN2 active
 */
void setPWM_MotorA(int8_t pwm_value) {
  if (pwm_value >= 0) {
    dir_motor_a = true;              // IN1 carries PWM signal
    pwm_motor_a = constrain(pwm_value, 0, 255);
  } else {
    dir_motor_a = false;             // IN2 carries PWM signal
    pwm_motor_a = constrain(-pwm_value, 0, 255);
  }
}

/**
 * Set PWM value for Motor B
 * @param pwm_value: 0-255 (0% to 100% duty cycle)
 *        Sign determines direction: positive -> IN3 active, negative -> IN4 active
 */
void setPWM_MotorB(int8_t pwm_value) {
  if (pwm_value >= 0) {
    dir_motor_b = true;              // IN3 carries PWM signal
    pwm_motor_b = constrain(pwm_value, 0, 255);
  } else {
    dir_motor_b = false;             // IN4 carries PWM signal
    pwm_motor_b = constrain(-pwm_value, 0, 255);
  }
}

/**
 * Stop both motors immediately
 */
void stopAllMotors() {
  pwm_motor_a = 0;
  pwm_motor_b = 0;
  digitalWrite(IN1, LOW);
  digitalWrite(IN2, LOW);
  digitalWrite(IN3, LOW);
  digitalWrite(IN4, LOW);
}

// PWM Frequency control
void setup() {
  Serial.begin(115200);  // Initialize serial communication at 115200 baud
  
  // Initialize hardware PWM interrupt system
  pwm_init();
  
  // Configure EN pins as outputs (controlled by interrupt)
  pinMode(EN_A, OUTPUT);
  pinMode(EN_B, OUTPUT);
  digitalWrite(EN_A, LOW);
  digitalWrite(EN_B, LOW);
  
  // Configure potentiometers as inputs
  pinMode(POT1, INPUT);
  pinMode(POT2, INPUT);
  
  // Initialize motors to stop (0% duty cycle - pins LOW, not attached to servo)
  pinMode(IN1, OUTPUT);
  pinMode(IN2, OUTPUT);
  pinMode(IN3, OUTPUT);
  pinMode(IN4, OUTPUT);
  digitalWrite(IN1, LOW);
  digitalWrite(IN2, LOW);
  digitalWrite(IN3, LOW);
  digitalWrite(IN4, LOW);
}

void loop() {
  if (Serial.available() > 0) {
    // Read the input character or string
    char inputChar = Serial.read();
    
    // Check if 'R' was received to send potentiometer values
    if (inputChar == 'R' || inputChar == 'r') {
      int pot1Value = analogRead(POT1);
      int pot2Value = analogRead(POT2);
      
      Serial.print(pot1Value);
      Serial.print(" ");
      Serial.println(pot2Value);
    }
    // Check if it's a digit (start of PWM command)
    else if (isdigit(inputChar) || inputChar == '-') {
      // Read the rest of the line
      String input = String(inputChar) + Serial.readStringUntil('\n');
      input.trim();
      
      // Parse the two integers
      int spaceIndex = input.indexOf(' ');
      
      if (spaceIndex > 0) {
        int dc1 = input.substring(0, spaceIndex).toInt();
        int dc2 = input.substring(spaceIndex + 1).toInt();
        
        // Map -100 to 100 range to -255 to 255 for PWM
        dc1 = constrain(dc1, -255, 255);
        dc2 = constrain(dc2, -255, 255);
        
        // Convert duty cycle percentage to PWM value (0-255)
        int pwm1 = map(dc1, -255, 255, -100, 100);
        int pwm2 = map(dc2, -255, 255, -100, 100);
        
        // Set motor PWM values
        setPWM_MotorA(pwm1);
        setPWM_MotorB(pwm2);
      }
    }
  }
}
  

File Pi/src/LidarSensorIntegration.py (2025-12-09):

"""
Integration module for LIDAR scans with beam range finder model.

Converts LIDAR scans to range measurements compatible with the probabilistic sensor model.
"""

import numpy as np
from ProbabilisticSensorModel import beam_range_finder_model, likelyhood_field_model


def lidar_scan_to_ranges(scan_data: np.ndarray, 
                         robot_pose: tuple,
                         num_beams: int = 360,
                         max_range: float = 5000) -> np.ndarray:
    """
    Convert raw LIDAR scan data to a normalized range array for sensor model.
    
    Interpolates scan data to a uniform angular distribution.
    
    Args:
        scan_data (np.ndarray): Nx3 array [angle, distance, quality]
        robot_pose (tuple): Robot pose (x, y, theta) - used for coordinate transformation
        num_beams (int): Number of beams to resample to (default: 360)
        max_range (float): Maximum range in mm (default: 5000)
    
    Returns:
        np.ndarray: Normalized range measurements (0-1 scale) for num_beams angles
    """
    if len(scan_data) == 0:
        return np.full(num_beams, 1.0)  # Return max range if no data
    
    # Extract angles and distances from scan
    angles = scan_data[:, 0]
    distances = scan_data[:, 1]
    
    # Normalize distances to 0-1 range
    normalized_distances = np.clip(distances / max_range, 0, 1)
    
    # Create uniform angular grid for resampling
    uniform_angles = np.linspace(0, 360, num_beams, endpoint=False)
    
    # Interpolate distances for uniform angles
    resampled_distances = np.interp(uniform_angles, angles, normalized_distances, 
                                    left=1.0, right=1.0)
    
    return resampled_distances


def lidar_scan_to_cartesian(scan_data: np.ndarray, 
                            robot_pose: tuple) -> np.ndarray:
    """
    Convert LIDAR scan to cartesian coordinates relative to world frame.
    
    Args:
        scan_data (np.ndarray): Nx3 array [angle, distance, quality]
        robot_pose (tuple): Robot pose (x, y, theta) in world frame
    
    Returns:
        np.ndarray: Nx2 array of [x, y] points in world frame
    """
    x_robot, y_robot, theta_robot = robot_pose
    
    angles_deg = scan_data[:, 0]
    distances_mm = scan_data[:, 1]
    
    # Convert angles to radians and add robot orientation
    angles_rad = np.radians(angles_deg) + theta_robot
    
    # Convert to cartesian in robot frame
    x_robot_frame = distances_mm * np.cos(angles_rad)
    y_robot_frame = distances_mm * np.sin(angles_rad)
    
    # Transform to world frame
    x_world = x_robot + x_robot_frame * np.cos(theta_robot) - y_robot_frame * np.sin(theta_robot)
    y_world = y_robot + x_robot_frame * np.sin(theta_robot) + y_robot_frame * np.cos(theta_robot)
    
    return np.column_stack([x_world, y_world])


def filter_scan_by_quality(scan_data: np.ndarray, 
                          min_quality: int = 5) -> np.ndarray:
    """
    Filter LIDAR scan points by signal quality.
    
    Args:
        scan_data (np.ndarray): Nx3 array [angle, distance, quality]
        min_quality (int): Minimum quality threshold (0-255)
    
    Returns:
        np.ndarray: Filtered scan data
    """
    if scan_data.shape[1] < 3:
        return scan_data
    
    quality = scan_data[:, 2]
    mask = quality >= min_quality
    return scan_data[mask]


def filter_scan_by_distance(scan_data: np.ndarray,
                           min_distance: float = 0,
                           max_distance: float = 5000) -> np.ndarray:
    """
    Filter LIDAR scan points by distance range.
    
    Args:
        scan_data (np.ndarray): Nx3 array [angle, distance, quality]
        min_distance (float): Minimum distance in mm
        max_distance (float): Maximum distance in mm
    
    Returns:
        np.ndarray: Filtered scan data
    """
    distances = scan_data[:, 1]
    mask = (distances >= min_distance) & (distances <= max_distance)
    return scan_data[mask]


def evaluate_scan_with_sensor_model(scan_data: np.ndarray,
                                    robot_pose: tuple,
                                    map_data,
                                    compute_from_map,
                                    num_beams: int = 360,
                                    max_range: float = 5000,
                                    sensor_params: dict = None) -> float:
    """
    Evaluate a LIDAR scan using the beam range finder model.
    
    Computes probability of observation given robot pose and map.
    
    Args:
        scan_data (np.ndarray): Nx3 array [angle, distance, quality]
        robot_pose (tuple): Robot pose (x, y, theta)
        map_data: Map data for sensor model evaluation
        compute_from_map: Function to compute expected range from map
        num_beams (int): Number of beams for evaluation
        max_range (float): Maximum range in mm
        sensor_params (dict): Sensor model parameters
                            - 'min_theta': minimum beam angle (default: -π/2)
                            - 'max_theta': maximum beam angle (default: π/2)
                            - 'sigma_hit': hit component std dev (default: 0.2)
                            - 'lambda_short': short component lambda (default: 0.1)
                            - 'z_hit': hit weight (default: 0.7)
                            - 'z_short': short weight (default: 0.1)
                            - 'z_max': max range weight (default: 0.1)
                            - 'z_rand': random weight (default: 0.1)
    
    Returns:
        float: Probability of observation given pose
    """
    if sensor_params is None:
        sensor_params = {}
    
    # Set defaults
    params = {
        'min_theta': sensor_params.get('min_theta', -np.pi/2),
        'max_theta': sensor_params.get('max_theta', np.pi/2),
        'sigma_hit': sensor_params.get('sigma_hit', 0.2),
        'lambda_short': sensor_params.get('lambda_short', 0.1),
        'z_hit': sensor_params.get('z_hit', 0.7),
        'z_short': sensor_params.get('z_short', 0.1),
        'z_max': sensor_params.get('z_max', 0.1),
        'z_rand': sensor_params.get('z_rand', 0.1),
    }
    
    # Convert scan to normalized ranges
    z_normalized = lidar_scan_to_ranges(scan_data, robot_pose, num_beams, max_range)
    
    # Denormalize for sensor model (convert back to actual mm)
    z_measured = z_normalized * max_range
    
    # Evaluate with beam range finder model
    prob = beam_range_finder_model(
        robot_pose,
        z_measured,
        map_data,
        compute_from_map,
        min_theta=params['min_theta'],
        max_theta=params['max_theta'],
        max_range=max_range,
        sigma_hit=params['sigma_hit'],
        lambda_short=params['lambda_short'],
        z_hit=params['z_hit'],
        z_short=params['z_short'],
        z_max=params['z_max'],
        z_rand=params['z_rand']
    )
    
    return prob
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

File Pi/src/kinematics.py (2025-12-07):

import numpy as np

def IK(v, w, L=0.081, D = 0.037):
    """
    Inverse Kinematics for a differential drive robot.
    
    Parameters:
    v : float
        Linear velocity (m/s)
    w : float
        Angular velocity (rad/s)
    L : float
        Distance between the wheels (m)
    D : float
        Diameter of the wheels (m)
        
    Returns:
    tuple
        Left and right wheel angular velocities (rad/s)
    """
    r = D / 2  # Radius of the wheel
    wl = (2 * v - w * L) / (2 * r)  # Left wheel angular velocity
    wr = (2 * v + w * L) / (2 * r)  # Right wheel angular velocity
    return wl, wr

def FK(wl, wr, L=0.081, D = 0.037):
    """
    Forward Kinematics for a differential drive robot.
    Parameters:
    wl : float
        Left wheel angular velocity (rad/s)
    wr : float
        Right wheel angular velocity (rad/s)
    L : float
        Distance between the wheels (m)
    D : float
        Diameter of the wheels (m)
        
    Returns:
    tuple
        Linear and angular velocities (m/s, rad/s)
    """
    r = D / 2  # Radius of the wheel
    v = r * (wl + wr) / 2  # Linear velocity
    w = r * (wr - wl) / (2*L)  # Angular velocity
    return v, w

def pot_readings_to_velocities(left_reading, right_reading, prev_left_reading, prev_right_reading, dt, bits=10, pot_range_rad=2*np.pi, pot_diameter_mm=10, wheel_diameter_mm=37):
    """
    Convert potentiometer readings to wheel angular velocities based on rate of change.
    
    Parameters:
    left_reading : int
        Current left integrated encoder count
    right_reading : int
        Current right integrated encoder count
    prev_left_reading : int
        Previous left integrated encoder count
    prev_right_reading : int
        Previous right integrated encoder count
    dt : float
        Time interval (s)
    bits : int
        Number of bits for potentiometer (10 bits = 0-1023, 1024 counts per full turn)
    pot_range_rad : float
        Range of potentiometer in radians (typically 2π for full rotation)
    pot_diameter_mm : float
        Diameter of potentiometer wheel (mm)
    wheel_diameter_mm : float
        Diameter of the actual wheel (mm)
        
    Returns:
    tuple
        (left_angular_velocity, right_angular_velocity) in rad/s (actual wheel velocities)
    """
    max_count = 2 ** bits  # 1024 for 10-bit (1024 counts = 1 full turn)
    
    # Gear ratio: potentiometer wheel to actual wheel
    gear_ratio = pot_diameter_mm / wheel_diameter_mm 
    
    # Calculate change in encoder counts (integrated, so no wraparound handling needed)
    delta_left = left_reading - prev_left_reading
    delta_right = right_reading - prev_right_reading
    
    # Convert count deltas to radians (1024 counts = 2π radians)
    angle_delta_left = delta_left * (pot_range_rad / max_count)
    angle_delta_right = delta_right * (pot_range_rad / max_count)
    
    # Calculate potentiometer angular velocities (rad/s)
    wl_pot = angle_delta_left / dt
    wr_pot = angle_delta_right / dt
    
    # Convert to actual wheel angular velocities using gear ratio
    # right wheel gets a mirror to account for orientation 
    wl = np.clip(wl_pot * gear_ratio, -1.8, 1.8)
    wr = np.clip(-wr_pot * gear_ratio, -1.8, 1.8)
    
    return wl, wr

def integrate_pose(v, w, dt, x=0, y=0, theta=0):
    """
    Integrate robot velocities to update pose.
    
    Parameters:
    v : float
        Linear velocity (m/s)
    w : float
        Angular velocity (rad/s)
    dt : float
        Time step (s)
    x : float
        Current x position (m)
    y : float
        Current y position (m)
    theta : float
        Current orientation (rad)
        
    Returns:
    tuple
        (x, y, theta) updated pose
    """
    x_new = x + v * np.cos(theta) * dt
    y_new = y + v * np.sin(theta) * dt
    theta_new = theta + w * dt
    
    return x_new, y_new, theta_new

def velocities_to_pwm(wl, wr, min_pwm=50, max_pwm=255, min_wheel_rad_s=0, max_wheel_rad_s=1.8):

    """
    Convert wheel angular velocities to PWM commands.
    
    Parameters:
    wl : float
        Left wheel angular velocity (rad/s)
    wr : float
        Right wheel angular velocity (rad/s)
    min_pwm : int
        Minimum PWM value (threshold for motor movement)
    max_pwm : int
        Maximum PWM value
    min_wheel_rad_s : float
        Minimum wheel angular velocity (rad/s) threshold
    max_wheel_rad_s : float
        Maximum wheel angular velocity (rad/s) corresponding to max PWM
        
    Returns:
    tuple
        (pwm_left, pwm_right) as integers
    """
    # Apply minimum velocity threshold
    wl = wl if abs(wl) >= min_wheel_rad_s else 0
    wr = wr if abs(wr) >= min_wheel_rad_s else 0
    
    # Normalize velocities to [-1, 1]
    norm_left = np.clip(wl / max_wheel_rad_s, -1, 1)
    norm_right = np.clip(wr / max_wheel_rad_s, -1, 1)
    
    # Convert to PWM with dead-band handling
    def norm_to_pwm(norm_vel):
        if norm_vel == 0:
            return 0
        elif norm_vel > 0:
            # Map [0, 1] to [min_pwm, max_pwm]
            return int(min_pwm + norm_vel * (max_pwm - min_pwm))
        else:
            # Map [-1, 0] to [-max_pwm, -min_pwm]
            return int(-min_pwm + norm_vel * (max_pwm - min_pwm))
    
    pwm_left = norm_to_pwm(norm_left)
    pwm_right = norm_to_pwm(norm_right)
    
    return pwm_left, pwm_right

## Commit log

2025-12-06 Add files via upload
    initial commit, contains the design files and preliminary python files for the RPi
    [2080 Extrusion.SLDPRT, LidarMount.STL, Motor Mount.STL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]
2025-12-07 finished the Motion model for the Mouse-Pi, and improved the arduino commander file
2025-12-09 added Lidar scanning, with beam model
2025-12-14 added ekf-slam to be used on the Mouse-Pi, still needs exploration critera, currently follows path planning (phase-II of the proj)
2025-12-14 added maze 3D part SW
    [Maze.SLDPRT]
2025-12-14 added world and model
    [maze.sdf, model.sdf]
2025-12-14 added MCL for Robot Pose init
    [trueworld.sdf]
2025-12-15 removing redundant sdf
    [trueworld.sdf]
2025-12-15 minor changes to gazebo sim
    [maze.sdf, model.sdf]
2025-12-15 new script + some results
    [trajectory.csv]
2025-12-15 fixed mismatch between the frames
    [maze.sdf, trajectory.csv]
